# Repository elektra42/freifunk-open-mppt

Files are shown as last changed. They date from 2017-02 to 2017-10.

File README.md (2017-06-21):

These are preliminary sources and CAD files from the
Freifunk-Open-MPP-Tracker project.

## SOME LICENSE-FOO:
This is a Open-Source and Open-Hardware project under General Public License
v2 and Creative Commons - Attribution - ShareAlike 3.0.
For more information, check out the LICENSE file.

## A QUICK OVERVIEW OF THE DIRECTORIES:

#### AVR-FUSES
Contains a XML configuration file to program the fuses of the AVR. I am
using the AVR dragon board and AVR-Burn-O-Mat software to program the fuses.

#### SCHEMATIC AND BOARD
Electronic CAD files and component libraries, made with KiCAD. KiCAD is a free and
open ECAD tool.  Due to the intend to provide a open hardware and open
software project for DIY home-brewers, I have decided to use a free and open
source ECAD software tool, too. It is my first project with KiCAD, though.

#### uC-SOURCECODE
AVR-GCC source and Makefile. 

## SOME NOTES ABOUT THIS DESIGN
Basically this hardware has two building blocks: 
The MPP controller section and the buck converter.

At the moment, the buck converter section is based on the el cheapo and
low-fi MC33063 controller chip.  It can easily be replaced by a faster and
more fancy switch converter IC to construct a more powerful and slightly more 
efficient buck converter section.  However, with the external powerful P-MOS
switches, the efficiency was already around 94% with the first prototype 
(measured at 2 Ampere output current).

One reason to replace the MC33063 might be noise. Under low load, the
MC33063 will skip pulses of the PWM, so the switching frequency becomes
audible. 

# External references

* https://wiki.freifunk.net/Freifunk-MPP-Tracker
* https://wiki.freifunk.net/Freifunk-Mast

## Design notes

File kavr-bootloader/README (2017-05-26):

About this project
==================

kavr is an open source AVR boot loader written entirely in C. 
kavr supports updating firmware by sending hexfiles to the AVR processor 
via its serial port. A three wire (RxD, TxD, GND) serial port connection 
is sufficient. 

No special software is required on the host PC. Any serial port terminal 
such as HyperTerminal, Minicom etc. supporting XON/XOFF work fine with 
kavr. Even DOS commands (MODE, COPY) can be used.

License
=======

This program is free software: you can redistribute it and/or modify
it under the terms of the GNU General Public License as published by
the Free Software Foundation, either version 3 of the License, or
(at your option) any later version.

This program is distributed in the hope that it will be useful,
but WITHOUT ANY WARRANTY; without even the implied warranty of
MERCHANTABILITY or FITNESS FOR A PARTICULAR PURPOSE.  See the
GNU General Public License for more details.

You should have received a copy of the GNU General Public License
along with this program.  If not, see <http://www.gnu.org/licenses/>.

How kavr works
==============

kavr is an AVR boot loader. At reset, the AVR processor executes the code at 
the reset vector. Depending on fuse settings, the reset vector points at 
address zero (if no boot loader is used) or the reset vector points at an 
address in upper flash memory. This is where kavr resides.

kavr itself needs to be programmed into the AVR processor using a hardware 
programmer such as any programmer supported by avrdude. Once installed, kavr 
interrupts the boot process for a short time checking for hexfile records 
received on the serial port. If so, kavr programs any received hexfile data
into flash memory and then boots the new firmware application. If there are 
no hexfile records detected on the serial port, kavr boots the old firmware 
application as usual.

How to update firmware with kavr
================================

In order to load new firmware into your board running the kavr boot loader
you need to first generate a firmware hexfile. If not already part of your
firmware makefile, add a command like this:

    avr-objcopy -j .text -j .data -O ihex firmware.elf firmware.hex

Then, connect your board with a PC using a serial port cable. Run the 
terminal program of your choice on the PC. Configure the serial port for
the baud rate hardcoded in your kavr boot loader and configure 8N1 protocol
and xon/xoff (aka software) handshake. Example (DOS command prompt):

    C:\>mode com1 baud=9600 DATA=8 PARITY=n STOP=1 XON=on

Next, reboot your board. Before the timeout hardcoded into your kavr boot 
loader, send your firmware hexfile to the serial port. kavr will flash the
new firmware and then run it. Example (DOS command prompt):

    C:\>copy firmware.hex com1:

Roll your own kavr
==================

Are you ready to put kavr on your board? I am assuming you've got a recent 
WinAVR installed on your development machine and that you know how to use 
it. You will also need a hardware programmer supported by avrdude. 

First, tell kavr a few things about your board (clock params, MCU type...).
Update the first parameters in the kavr Makefile with your parameters. Here 
you will also need to define settings for serial port baud rate and boot 
loader timeout. Which one you choose depends on the capbilities of your board 
and its typical firmware application. I typically use 9600 baud and 1 second
timeout. Higher baud rates might or might not work, depending on your board's 
clock configuration. 

Then, build kavr for your board. Type "make". If there are any errors in the
make process, go fix them. The makefile displays the amount of flash used for
kavr (avr-size, the number under "text" matters). This number should be 
compatible with your boot loader start address (BOOTADDR) setting in the 
makefile and with your fuse settings. More specifically, BOOTADDR+size must 
not exceed your flash address space. Currently the code fits into 512 bytes 
(256 words) but this number may vary with your settings and with the compiler 
version you are using. Always double check that kavr fits into your flash.

Next, hook up your hardware programmer with your board. Run "make flash". 
This installs kavr into the boot loader area of your board. Now, tell AVR
to boot kavr instead of the firmware by programming its fuses for kavr mode.
Run "make fuse". 

Done! kavr should now be a happy boot loader on your system. Please note 
that when you flash kavr, avrdude also erases your firmware image so you 
will need to re-install your firmware.

Bugs/Enhancements?
==================

kavr is open source software. It's licensed under GPL. The latest source 
code is available on Sourceforge (http://kavr.sourceforge.net).
Please report any problems or feedback any proposals for enhancement using
the Sourceforge tracker system.

Donate
======

If you like kavr and if you use kavr for a project that you (or your 
employer) make money with, then you (or your employer) may want to consider 
donating a few bucks in return.

Your donation will help offsetting development costs, hardware purchases, 
and other expenses (like travel to conferences) in support of ongoing 
development of the software.

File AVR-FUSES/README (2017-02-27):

The XML file contains the fuse AVR description for the free AVR8-Burn-O-Mat tool.

URL: http://avr8-burn-o-mat.aaabbb.de/

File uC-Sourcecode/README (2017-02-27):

These files are for AVR-GCC. 

USE:

* Run 
$ make 
to compile

* Run 
$ make program
to write into the uC.

Programmer is set to avr-dragon by default. You can change this in the
Makefile. 

NOTE: You have to program the ATMega 8 fuses first.

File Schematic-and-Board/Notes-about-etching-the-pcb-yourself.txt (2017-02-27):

Etching the board yourself
++++++++++++++++++++++++++

This is cheap and fun and you don't have to wait for the pcb manufacturer to make your board.

The back side of the pcb is ground. I haven't filled the backside with copper yet. You can make a DIY 2-layer copy of the pcb board by etching only the top side. If you do that, you have to manually remove the copper around the pin holes of the pin headers that aren't connected to the ground on the back side of the pcb. You can do that manually with a relatively large drill by hand. Drill the small holes (0,8mm diameter), then use the large drill to cut away the copper by hand. 

The GND pins of the pin headers need to be soldered on the top and the bottom. The other pins need to be soldered at the top.

On the two protoype boards that I'm currently testing and experimenting with, I made the vias by drilling holes and soldering wire bridges to both sides.

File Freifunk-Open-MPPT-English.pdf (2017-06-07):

# Freifunk-Open-MPPT

## (MPPT: Maximum Power Point Tracker)

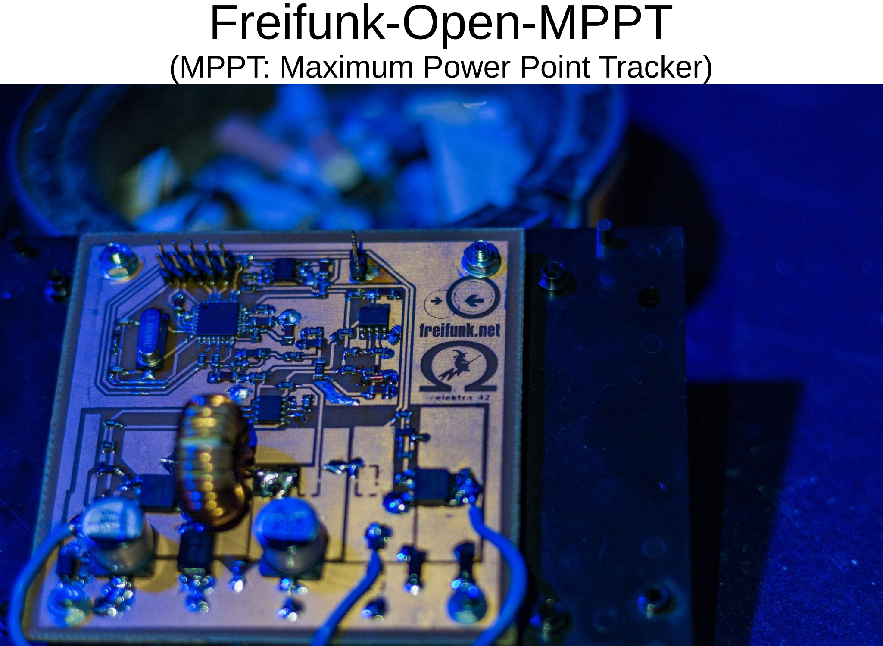
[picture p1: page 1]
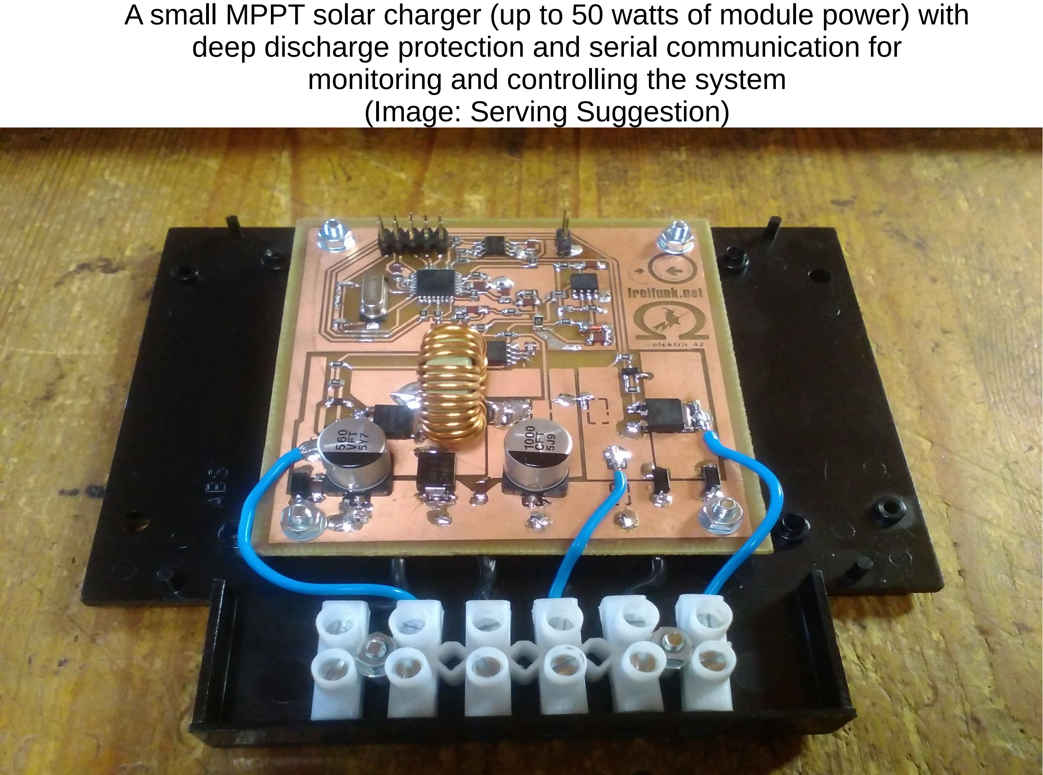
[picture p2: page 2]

A small MPPT solar charger (up to 50 watts of module power) with deep discharge protection and serial communication for monitoring and controlling the system (Image: Serving Suggestion)

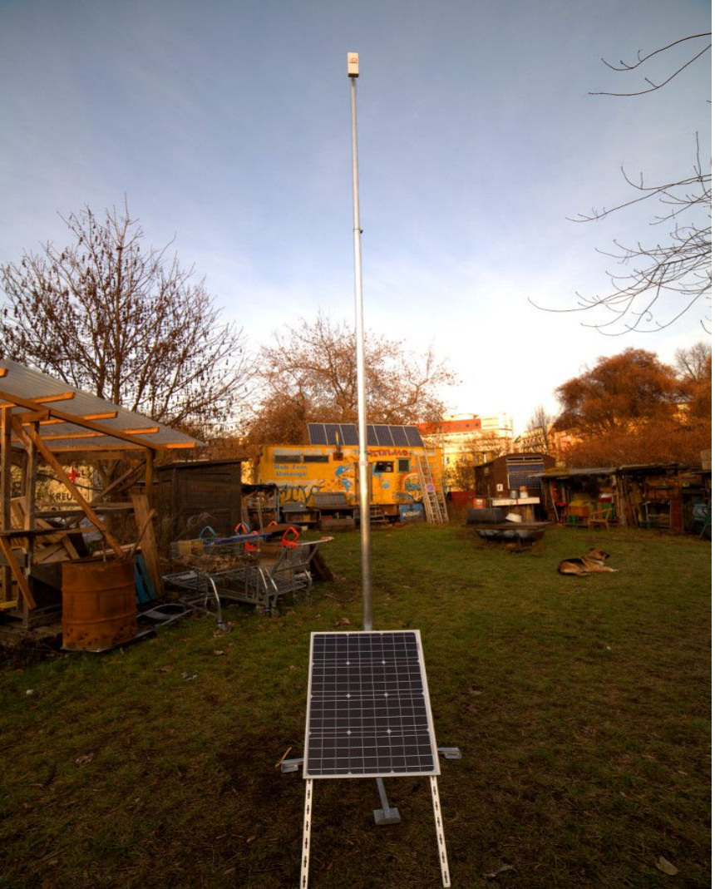
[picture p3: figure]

## Solar charger & measurement data acquisition for resilient and energy autonomous wireless

mesh nodes.

## Increased energy yield through Maximum Power Point Tracking

## Image: Mobile Freifunk mast

### Some applications for energy independent mesh nodes

### * Refugee camps

### * Resilient communication infrastructure / networks in crisis and disaster situations

### * Informal settlements in developing countries (controller provides electricity for smartphone, tablet, light, radio,... and mesh node on the roof)

### * Community network nodes at elevated locations without current, e.g. Barn roof, on the hill / mountain between two places that blocks the Fresnel zone

### * General purpose solar charger

* You name it.

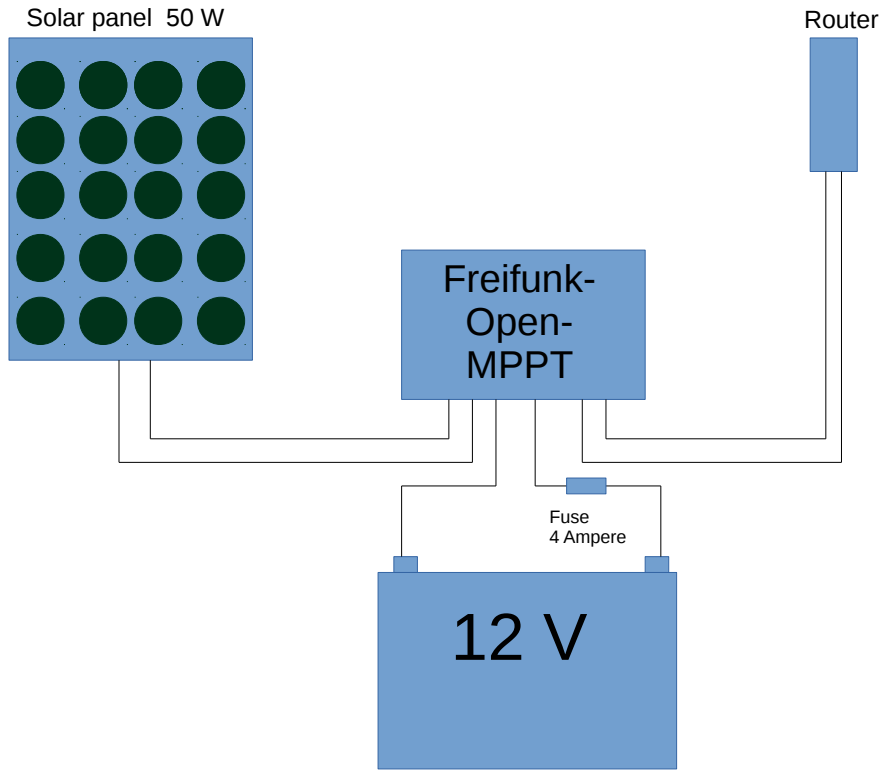
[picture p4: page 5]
Solar panel 50 W; Freifunk- Open- MPPT; Router; Fuse 4 Ampere

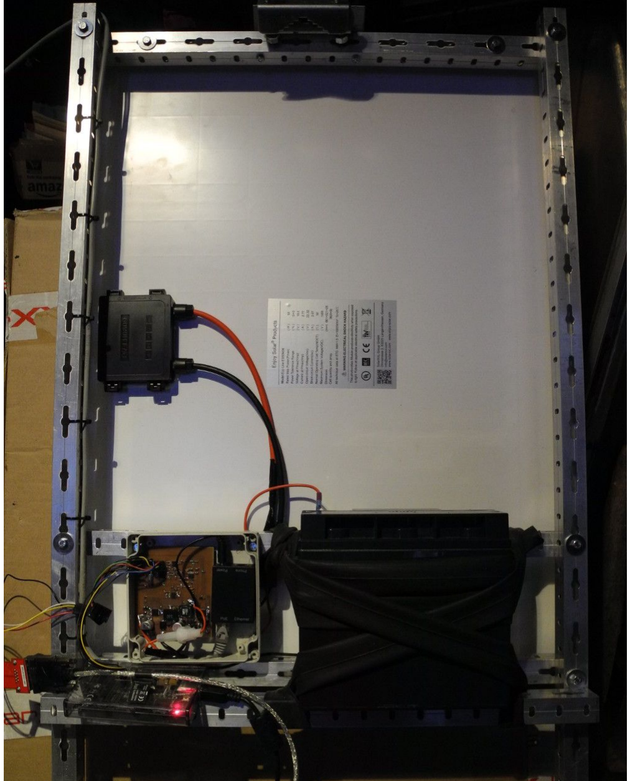
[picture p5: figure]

## Special features of the Freifunk-Open-MPPT:

* AVR-GCC Source code for μC firmware under GNU-GPL
* Open source CAD files for KiCAD (open-source -CAD program for Linux, Mac,
Windoze)
* MPPT design of the solar controller increases energy yield (94.5% efficiency)

* Communicates operating data via serial RS232 interface (3.3 volt level) e.g. To the connected router with the mesh network
* Uses only proven and easily available standard components
* Board layout, which allows the two-layer PCB in the DIY process itself (Milling or etching in the maker space on only one board side)
* Microprocessor-controlled: AVR ATmega8 with 1kByte RAM and 8kByte Flash (!)
* Firmware update via serial interface and bootloader, easy to do via serial upload (cat main.hex> / dev / tty ***) within 8 seconds after activating the power supply

# MPPT – what?!

Electric power in watts is voltage times Power:

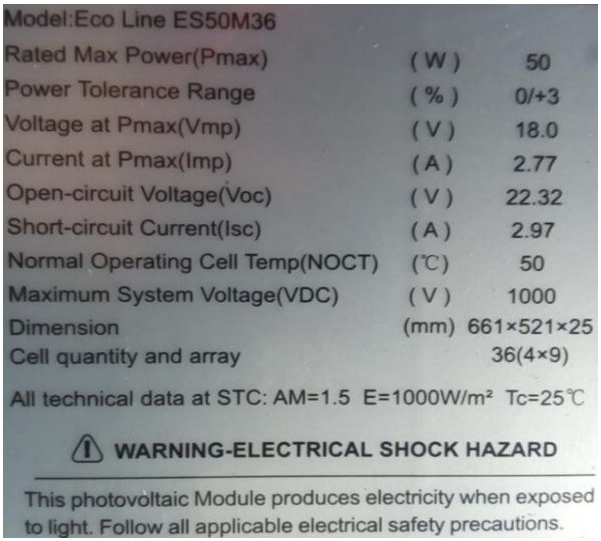
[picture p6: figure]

Watt = Volt * Ampere

50 W solar module specs:

Battery voltage = 11.3 - 14.9V

### 50 Watt Solar module at MPP:

### 50 W = 18V * 2.77A

### 50 Watt solar module

connected to 12 V battery
voltage without MPPT:

### 33.24 W = 12 V * 2.77 A

### 50 Watt Solar module with

Freifunk-Open-MPPT (94.5%
efficiency):

### 47.12 W = 18V * 2.77A * 0.945

## MPPT in operation

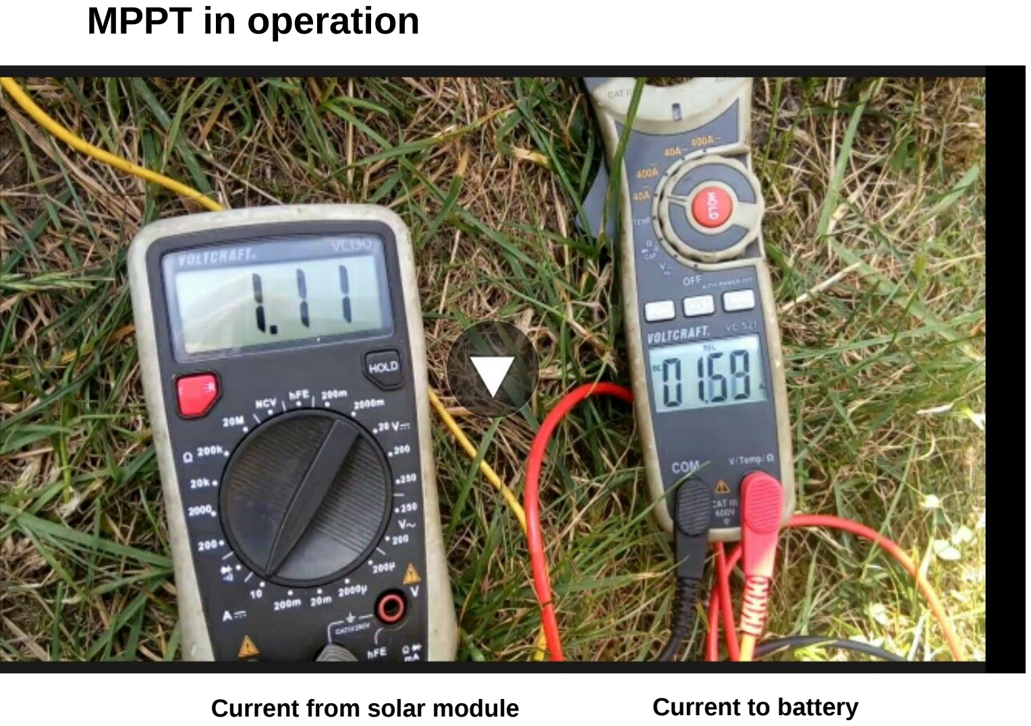
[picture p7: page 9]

Current from solar module | Current to battery

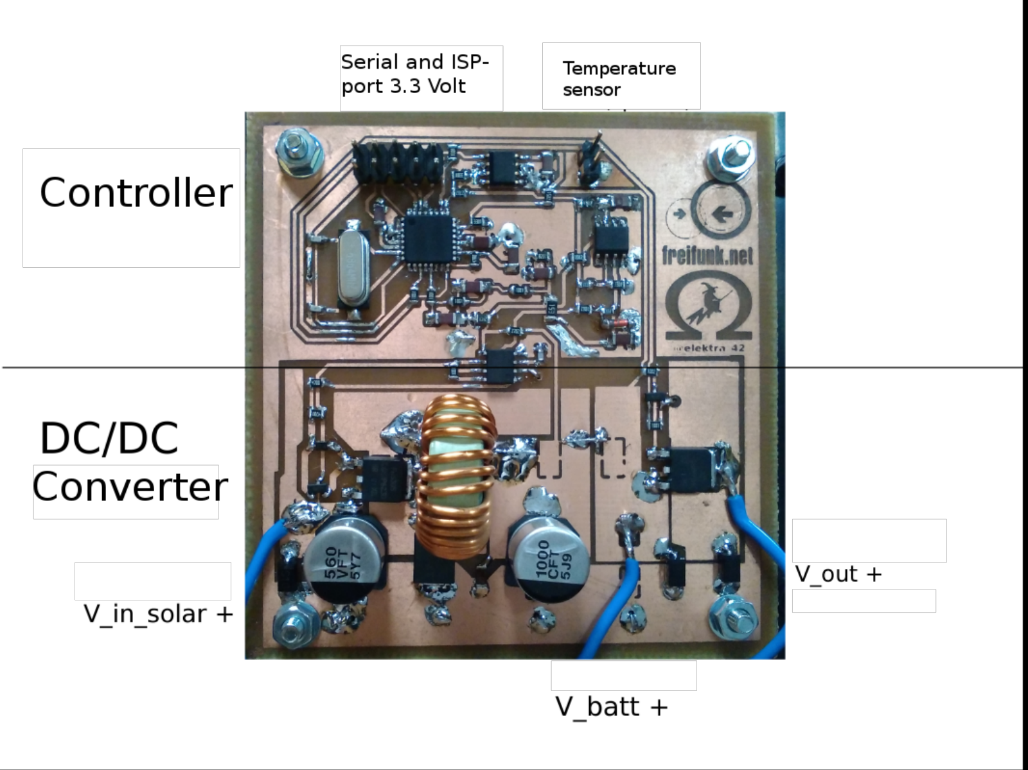
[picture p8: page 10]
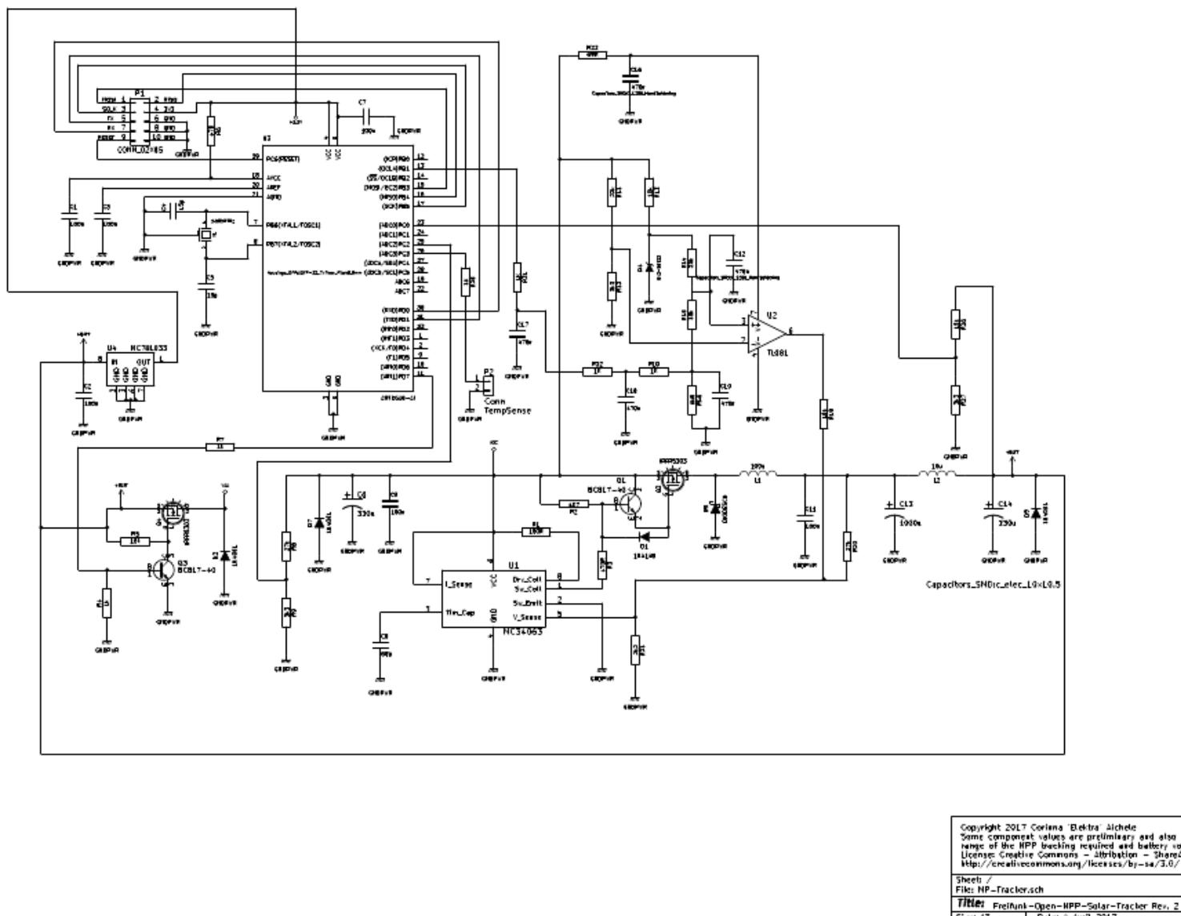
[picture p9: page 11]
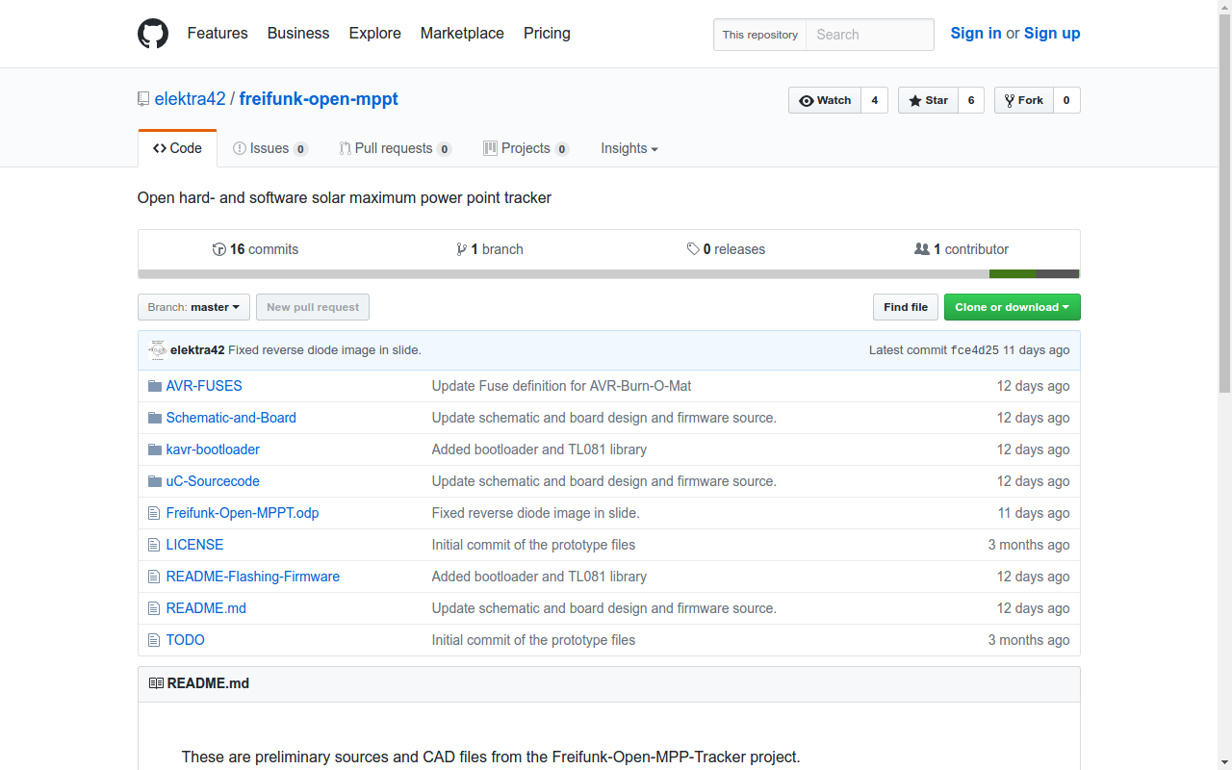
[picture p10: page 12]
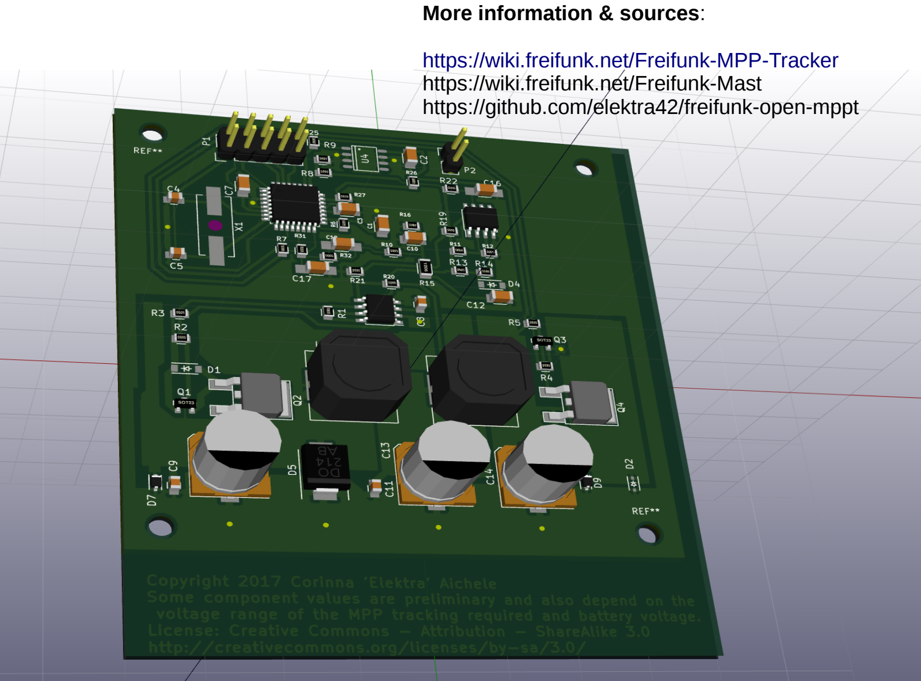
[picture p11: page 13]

More information & sources:

https://wiki.freifunk.net/Freifunk-MPP-Trackerhttps://wiki.freifunk.net/Freifunk-Masthttps://github.com/elektra42/freifunk-open-mppt

# Thank you for your attention!

# @elektra_42

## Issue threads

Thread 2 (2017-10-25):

not really an issue but ...

5chufti, 2017-10-25:
it would be nice to have some explanation about the function around PB1 - R/C filter/integrator - U2 - R11..R15/D4 - Vsense. I looked at the "homepage", found good explanation about mppt, but none about theory behind "feedback/control" circuitry.

elektra42, 2017-10-26:
The R/C filter network provides a stable and low noise reference voltage for the V+ input of the OP-Amp, which is controlled by the PWM output of the µC. Since the OP-Amp has no symmetrical power supply, a bit of trickery at the voltage divider is necessary to put the PWM signal of the µC, which can not exceed 3.3 V, to a level that is high enough about GND to be compared by the V- input of the OP-Amp, which is connected to the solar input rail via a voltage divider. If the V+ input is greater than the V- input of the OP-Amp, the input solar voltage is lower than the set MPP point. The output of the OP-Amp goes up, signalling the DC/DC buck controller chip MC33063 via its reference pin that the set output voltage has been exceeded. In response, the MC33063 will reduce the pulse-pause-ratio of the PWM in the MC33063, hence the current load on the solar module will go down and the solar input voltage rises to the point where V- at the Op-amp becomes greater then V+. V out of the OP-Amp goes down: So here we have a control loop, controlling the MPP voltage.

By controlling the PWM output of the µC, the MPP input voltage can be controlled by the µC firmware.

5chufti, 2017-10-26:
thank you for the quick answer.

Closed 2017-10-26.

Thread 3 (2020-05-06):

100W or even more - which parts to be changed on the PCB?

fafu, 2020-05-06:
Hi all,
since 100W solar panels are only slightly more expensive than a 50W panel I am curious which parts to be changed. If I remember right, elektra told me during a workshop it is possible.

Thanks :)

elektra42, 2020-05-10:
You should replace C6, Q2 and C13. Replace C6 with a polymer electrolytic capacitor, they have lowest ESR compared to the stock low ESR capacitor. Recommended: PANASONIC SVPF 330µ 25 V. Replace C13  with a polymer electrolytic capacitor. Recommended: PANASONIC SVPF 1000µ 16V , Replace Q2 with AO D403 MOSFET, P-CH, 30V, 70A, 90W, DPAK.

Make sure to not exceed 25 V idle (open connector = Voc) solar panel voltage in sunny, but freezing cold climate (sunny winter day). The absolute maximum voltage limit of SVPF 330µ 25 V is 29 V. You should avoid getting close to that limit. If you risk 26 or even 27 V idle under rare conditions, that might be ok. Keep an eye on L1, on my tuned FF-OpenMPPTs, I have used a larger ring power core with thicker wire, so I'd recommend that, too. But you might get away with the stock L1. If you buy a bigger ring power core L1 could be winded to ~16µH, if possible with thicker insulated copper wire. The thicker the wire you can make fit, the better (more efficient).

As I sidenote: I have a new design with a ESP32 build in and prepared for more power. https://github.com/ISEMS/ISEMS-ESP32

Have fun and success with soldering.

Sunshine!
Elektra

elektra42, 2020-05-10:
One more note: The material for the ring power core is critical. So don't use just a random ring power core that comes your way. I recommend Micrometals/Amidon power core material type "-18", a T 94-18 should handle the power well.

fafu, 2020-05-17:
Thank you for the helpful information

Closed 2020-05-17.

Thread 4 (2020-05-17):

Max current on v-out?

fafu, 2020-05-17:
Hi,
what is the max current which can be drawn on v-out?

elektra42, 2020-05-17:
RDS_on is 0.06 Ohm for the stock IRF5305. For a output current of 5 Ampere this means a voltage drop of 0.3 V and a power loss of 1.5 Watt. You can upgrade to a AO D403 here, too, which has 0.008 Ohm RDS_on. That results in a voltage drop of 0.08 V at 10 Ampere, hence a power loss of 0.8 Watt. I recommend not to go higher than that.

Closed 2020-05-17.

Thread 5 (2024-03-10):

[Feature] DC-Mini-Grid input/output?

T-X, 2024-03-10:
It'd probably be out of scope for this project right now, but had been wondering if such an addition would be technically doable or what the challenges could be to achieve it:

Add an additional two +/- pins which could be used to interconnect multiple Freifunk Open-MPPT devices to a distributed mini DC grid. If one or more devices have batteries charged to a high State-of-Charge (like >75%?) they'd provide it to other devices with batteries with a low State-of-Charge (<50%?).

1) Should likely be using 56VDC - 60VDC to be able to achieve a bit of distance, to reduce losses?
2) Would it maybe make sense to somehow limit the current in a smart way to reduce losses (and as a safety feature, to reduce the risk of running too much current through the wires?)?

I'm also wondering what the advantages and disadvantages would be to design it in a "Hub mode" where every device connects to the same line (1:n). Versus a "Switch mode" with multiple +/- pairs on a device and then only peer-to-peer 1:1 connections. (The latter would probably make 2) as a safety feature easier to implement and monitor, but would also be more costly?)

**Problems this feature could solve**

For instance in a trailer park scenario involving trees not everyone has the same amount of usable space for solar panels available. Also it's not always easy to estimate the needed battery and panel sizes in advance, power requirements can change over time. Thirdly, this could make it more easy/flexible/manageable to use/add multiple Open-MPPT devices to locally power multiple Freifunk routers, laptops, Raspberry Pis etc.?

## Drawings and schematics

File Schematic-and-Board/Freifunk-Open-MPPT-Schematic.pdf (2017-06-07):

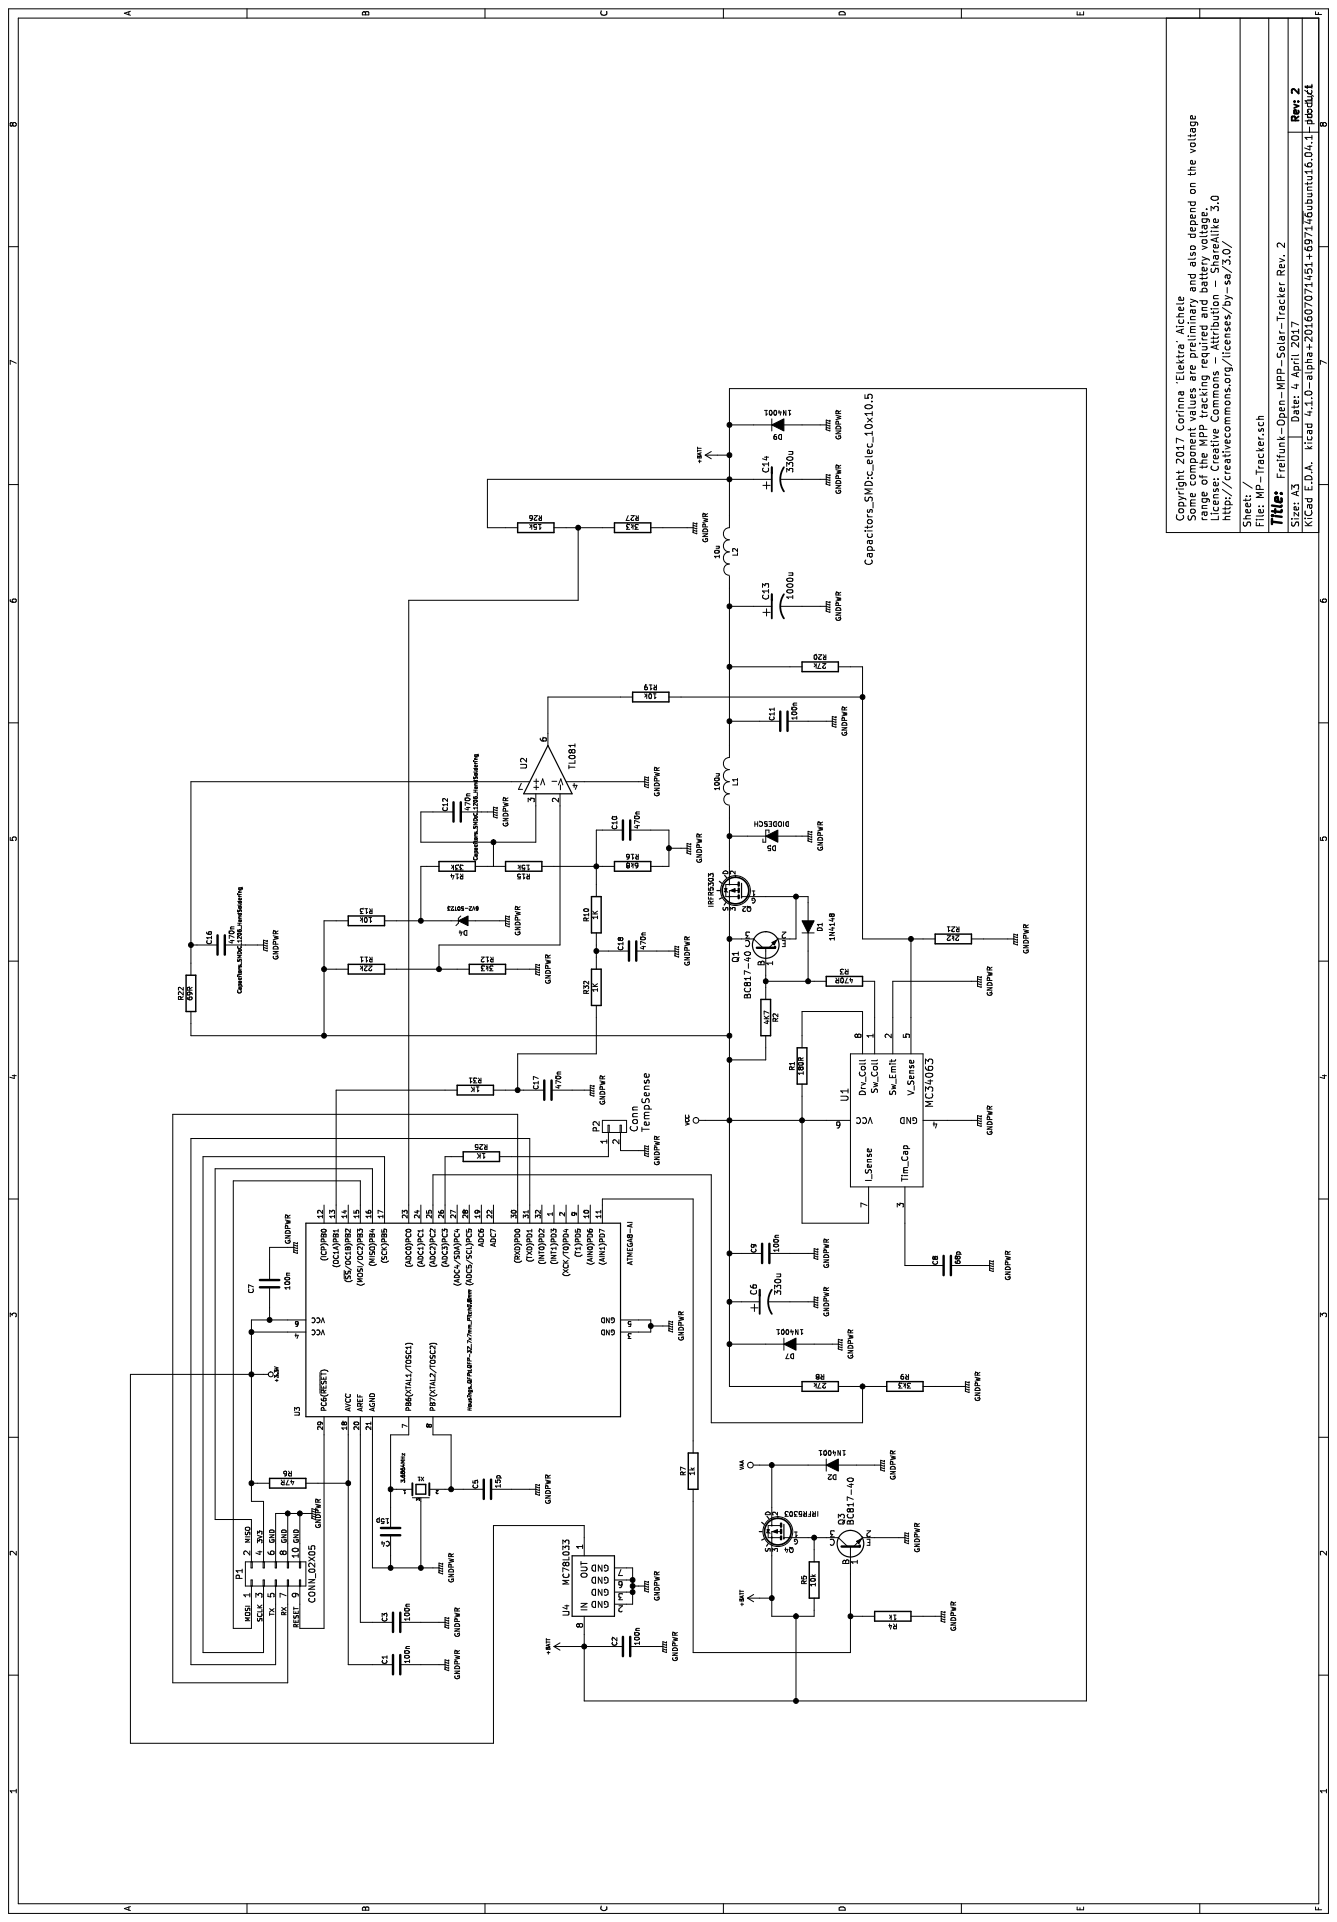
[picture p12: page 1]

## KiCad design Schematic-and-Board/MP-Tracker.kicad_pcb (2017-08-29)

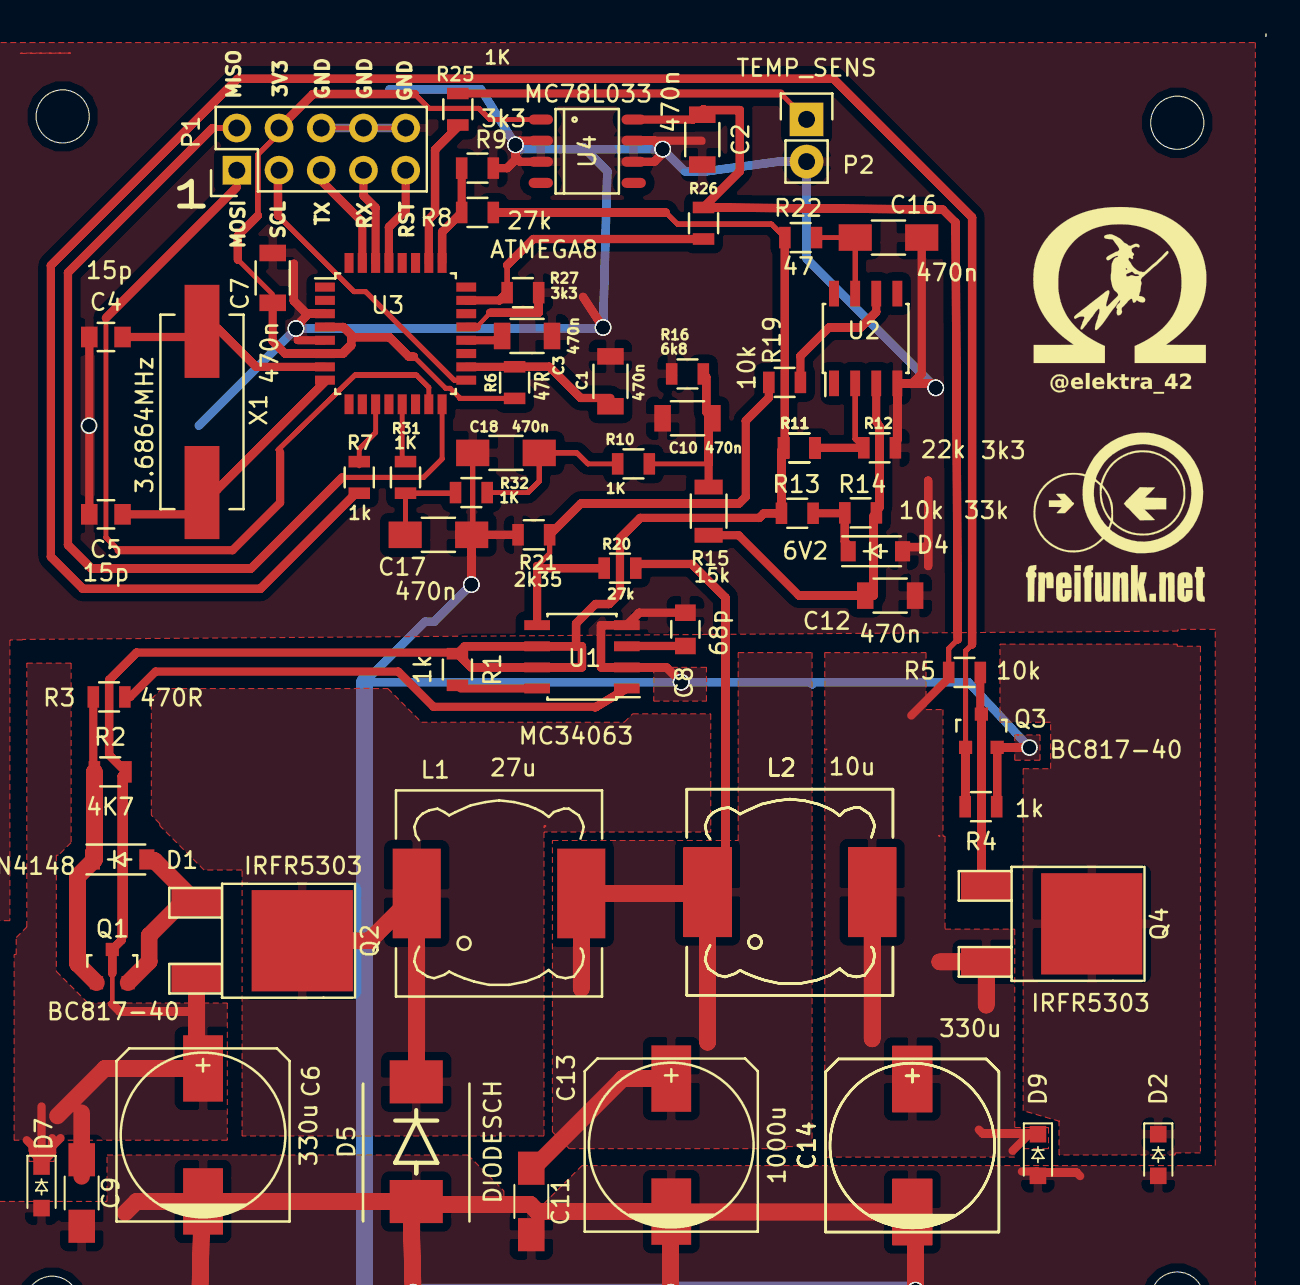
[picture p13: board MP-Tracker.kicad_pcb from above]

Board: 2 copper layers, 64 parts (0 on the bottom side), 39 nets.

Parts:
C1, C2, C3, C7, C10, C12: 470n; C_1206
C4, C5: 15p; C_0805
C6, C14: 330u; c_elec_10x10
C8: 68p; C_0805
C9, C11: 100n; C_1206_HandSoldering
C13: 1000u; c_elec_10x10
C14#2: c_elec_10x10
C16, C17, C18: 470n; C_1206_HandSoldering
D1: 1N4148; SOD-123
D2, D7, D9: 1N4001; D_SOD-323_HandSoldering
D4: 6V2; SOD-123
D5: DIODESCH; DO-214AB
L1: 27u; Choke_SMD_12x12mm_h8mm
L2: Choke_SMD_12x12mm_h8mm
L2#2: 10u; Choke_SMD_12x12mm_h8mm
P1: Pin_Header_Straight_2x05
P2: TEMP_SENS; Pin_Header_Straight_1x02
Q1, Q3: BC817-40; SOT-23
Q2, Q4: IRFR5303; TO-252-2Lead
R1, R4, R7: 1k; R_0805
R2: 4K7; R_0805
R3: 470R; R_0805
R5, R13, R19: 10k; R_0805
R6: 47R; R_0805
R8, R20: 27k; R_0805
R9, R12, R27: 3k3; R_0805
R10, R25, R31, R32: 1K; R_0805
R11, R11#2: 22k; R_0805
R14: 33k; R_0805
R15: 15k; R_1206
R16: 6k8; R_0805
R21: 2k35; R_0805
R22: 47; R_0805
R26: 15k; R_0805
U1: MC34063; SOIC-8_3.9x4.9mm_Pitch1.27mm
U2: TL081; SOIC-8-1EP_3.9x4.9mm_Pitch1.27mm
U3: ATMEGA8; LQFP-32_7x7mm_Pitch0.8mm
U4: MC78L033; SO-8
X1: 3.6864MHz; Crystal_HC49-SD_SMD

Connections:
+3.3V: C7.1, P1.4, R6.1, U3.4, U3.6, U4.1
+BATT: C2.1, C14.1, C14#2.1, D9.1, L2.2, L2#2.2, Q4.3, R5.1, R26.1, U4.8
GNDPWR: C1.2, C2.2, C3.2, C4.1, C5.2, C6.2, C7.2, C8.2, C9.2, C10.2, C11.2, C12.2, C13.2, C14.2, C14#2.2, C16.2, C17.2, C18.2, D2.2, D4.2, D5.1, D7.2, D9.2, P1.6, P1.8, P1.10, P2.2, Q3.2, R4.1, R9.2, R12.2, R16.2, R21.2, R27.2, U1.2, U1.4, U2.4, U3.3, U3.5, U3.21, U4.2, U4.3, U4.6, U4.7
unnamed: C1.1, R6.2, U3.18
unnamed: C3.1, U3.20
unnamed: C4.2, U3.7, X1.1
unnamed: C5.1, U3.8, X1.2
unnamed: C8.1, U1.3
unnamed: C10.1, R10.2, R15.1, R16.1
unnamed: C11.1, C13.1, L1.2, L2.1, L2#2.1, R20.1
unnamed: C12.1, R14.1, R15.2, U2.3
unnamed: C16.1, R22.2, U2.7
unnamed: C17.1, R31.2, R32.1
unnamed: C18.1, R10.1, R32.2
unnamed: D1.2, Q1.2, Q2.1
unnamed: D1.1, Q1.1, R2.1, R3.1
unnamed: D4.1, R13.2, R14.2
unnamed: D5.2, L1.1, Q2.2
unnamed: P1.1, U3.15
unnamed: P1.2, U3.16
unnamed: P1.3, U3.17
unnamed: P1.5, U3.31
unnamed: P1.7, U3.30
unnamed: P1.9, U3.29
unnamed: P2.1, R25.2
unnamed: Q3.1, R4.2, R7.1
unnamed: Q3.3, Q4.1, R5.2
unnamed: R1.2, U1.8
unnamed: R3.2, U1.1
unnamed: R7.2, U3.11
unnamed: R8.2, R9.1, U3.25
unnamed: R11.2, R11#2.2, R12.1, U2.2
unnamed: R19.1, U2.6
unnamed: R19.2, R20.2, R21.1, U1.5
unnamed: R25.1, U3.26
unnamed: R26.2, R27.1, U3.23
unnamed: R31.1, U3.13
VAA: D2.1, Q4.2
VCC: C6.1, C9.1, D7.1, Q1.3, Q2.3, R1.1, R2.2, R8.1, R11.1, R11#2.1, R13.1, R22.1, U1.6, U1.7

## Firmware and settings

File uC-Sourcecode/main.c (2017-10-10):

/* **********************************************************************
 * AVR-GCC source code for Freifunk-Open-MPP-Solar-Tracker
 * Copyright (C) 2017  by Corinna 'Elektra' Aichele 
 * 
 * This file is part of the Open-Hardware and Open-Software project 
 * Freifunk-Open-MPP-Solar-Tracker.
 * 
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
 * This source code is distributed in the hope that it will be useful,
 * but WITHOUT ANY WARRANTY; without even the implied warranty of
 * MERCHANTABILITY or FITNESS FOR A PARTICULAR PURPOSE.  See the
 * GNU General Public License for more details.
 * You should have received a copy of the GNU General Public License
 * along with this source file. If not, see http://www.gnu.org/licenses/. 
 *************************************************************************/


#include <avr/io.h>
#include <stdlib.h>
#include <util/delay.h>
#include <avr/sleep.h>
#include <avr/interrupt.h>

/* UART init */

#ifndef F_CPU
#warning "F_CPU not defined in Makefile. Using 3.686400 MHz"
#define F_CPU 3686400UL 
#endif

/* Define baud rate for serial port */
#define BAUD 9600UL

/* Calculate UART BAUD register setting */
#define UBRR_SETTING ((F_CPU+BAUD*8)/(BAUD*16)-1)



    uint16_t v_out_adcval;
    uint16_t solar_in_adcval;
    uint16_t v_in_value;
    uint16_t v_out_value;
    char vo[] = "";
    
    /* All Voltages are in mV */
    
    // v_out_max = Charge end voltage in mV at 25 degrees Celsius for sealed VRLA 12 V battery (Kung-Long, Panasonic and the like)
    // Manufacturers recommend 14.7 V to 14.9 V charge end voltage for cyclic use, 13.6 V to 13.8 V for standby use
    // As a solar system is a mix between cyclic and standby use, 14.15 V - 14.3 V charge end voltage is probably a good compromise.
    
    uint16_t v_out_max = 14200; 
    
    // v_load_off = Low voltage disconnect voltage in mV. Battery wear depends on depth-of-discharge. 11.7 Volt is moderate, discharging will stop at approximately 15% charge. For extended battery life, v_load_off can be increased to 12.1 V (~50% charge). Lead acid batteries have no memory effect.

    uint16_t v_load_off = 11700; 
    
    // v_load_on = Low voltage disconnect enable voltage in mV. v_load_off and v_load_on are building a hysteresis so the system doesn't turn the load on and off repeatedly. 
    
    uint16_t v_load_on = 12300; 
    
    
    uint16_t v_mpp_estimate = 0;
    uint8_t step = 0x1;
    volatile uint16_t ticks = 0;
    double ptc_resistance;
    double resistor_voltage;
    double temperature;
    double temp_deviation;
    uint16_t v_out_max_temp;
    uint16_t old_mpp_pwm_val =0;
    uint16_t count;
    

/* ADC init */
void ADC_Init(void)
{
  // Reference: Use Vcc as AVcc
  ADMUX = (1<<REFS0);    
  
  /* Bit ADFR ("free running") in ADCSRA is zero 
   * by default which means single conversion */
  
  // Enable frequency divider
  ADCSRA = (1<<ADPS1) | (1<<ADPS0);
  // set ADC enable
  ADCSRA |= (1<<ADEN);                             

  /* After activating the ADC, a warm-up readout is 
   * recommended to increase accuracy */
  
  // run ADC readout
  ADCSRA |= (1<<ADSC);
  // wait until finished
  while (ADCSRA & (1<<ADSC) ) {               
  }
}



/* ADC read, single conversion */
uint16_t ADC_Read( uint8_t channel )
{
  /* Select ADC channel */
  ADMUX = (ADMUX & ~(0x1F)) | (channel & 0x1F);
  // single conversion
  ADCSRA |= (1<<ADSC);
  // wait for conversion until finished
  while (ADCSRA & (1<<ADSC) ) {             
  }
  return ADCW;
}



/* Multiple ADC readouts, calculate average  */
uint16_t ADC_Read_Avg( uint8_t channel, uint8_t nsamples )
    {
    uint32_t sum = 0;

    for (uint8_t i = 0; i < nsamples; ++i ) {
    sum += ADC_Read( channel );
            }

    return (uint16_t)( sum / nsamples );
    }


/* UART init */
void uart_tx_enable(void)
    {
        UBRRH = UBRR_SETTING >> 8;
        UBRRL = UBRR_SETTING & 0xFF;
	
	// enable UART TX
        UCSRB |= (1<<TXEN);
	// select asynchronous mode 8N1 
        UCSRC = (1<<URSEL)|(1<<UCSZ1)|(1<<UCSZ0);  // asynchronous mode 8N1 
        }

        
/* UART disable */
void uart_tx_disable(void)
    {
        UCSRB |= (0<<TXEN);  // disable UART TX 
        }
  
  

/* UART send single character */
int uart_putc(unsigned char c)
    {
        // wait until transmit is possible 
        while (!(UCSRA & (1<<UDRE)))  
        {
        }                             
	// send character
        UDR = c;                      
        return 0;
        }

    
/* UART send string */
void uart_puts(char *s) 
    {
        while (*s)
        {   //transmit as long as  *s != '\0' 
            uart_putc(*s);
            s++;
        }
    }
    

    
/* Low voltage disconnect */                    
void low_voltage_disconnect (uint16_t voltage)
    {
	
        // Exceeding v_load_on enables load
	if (voltage > v_load_on) 
        { 
        PORTD = (1<<PD7) ;
        }
        
        // Below v_load_off, disable load      
        if (voltage < v_load_off) 
        {
        PORTD = (0<<PD7);
        }
        
        // Let the world know (if it has power to read the data ;)
        if (PORTD == (1<<PD7))
        {
        uart_puts("Load enabled\r\n");
        }
        else 
        {
        uart_puts("Load disabled\r\n");
        }
                    
    }

/* Power saving sleep routine based on counter/timer2 
 * Sleep (idle) time with 3.684 MHz clock is 70.6ms */
void interrupt_based_sleep (void)
	{
  
	TIFR |= (1<<TOV2);
	// enable counter2 overflow interrupt
	TIMSK |= (1<<TOIE2);
	// Set counter2 to zero
	TCNT2 = 0x00;
	sei();  
	set_sleep_mode(SLEEP_MODE_IDLE);
	sleep_enable();
	sleep_mode();
	cli();
	}

/* ISR TIMER2 overflow routine */
ISR(TIMER2_OVF_vect)
      {
      return;
      }
      
/* Measure battery voltage */
 uint16_t measure_v_out(void) {
	v_out_adcval = ADC_Read_Avg(0, 32); 
	v_out_value = (17.57 * v_out_adcval);
        return v_out_value;
}

/* Measure solar input voltage */
uint16_t measure_v_in(void) {
        // Read ADC channel 2, calculate average from 10 readings
        solar_in_adcval = ADC_Read_Avg(2, 32);  
        v_in_value = (29.13 * solar_in_adcval);
        return v_in_value;
    
}

void read_temp_sens (void)
    {
        /* Read voltage of ptc resistance in voltage divider
         * Suggested PTC temperature sensor model:  KTY 81-210
         * R2 = PTC resistance at 25 degrees Celsius 2000 Ohm +- 20 Ohm
         * R1 = 1300 Ohm 
         * R2 = R1 / ((3300mV / resistor_voltage) - 1) 
         * all values in mV */
        
        
        resistor_voltage = (ADC_Read_Avg(3, 8)) * 3.22265 ;
        
        if (resistor_voltage > 3200) {
        uart_puts ("No temperature sensor available. \r\n");
        return;
        }
        
         uart_puts("PTC sensor voltage: ");
	 itoa(resistor_voltage, vo, 10 );
	 uart_puts(vo);
	 uart_puts (" mV\r\n");
         ptc_resistance = 1300 /  ((3300 / resistor_voltage) - 1);

         uart_puts("PTC sensor resistance: ");
         itoa(ptc_resistance, vo, 10 );
         uart_puts(vo);
         uart_puts (" Ohm\r\n");
       
        // KTY 81-210 is not very accurate.
        // Best accuracy at 40 degrees Celsius
         
        temperature = -30 + ((ptc_resistance - 1247) / 14.15);
        
        uart_puts("Temperature ");
        dtostrf (temperature, 1, 1, vo);
        uart_puts(vo);
        uart_puts (" degrees Celsius\r\n");
        
        /* Calculate and adjust charge end voltage depending on 
        battery temperature for voltage regulated lead acid battery chemistry 
        Correction factor 5 mV per cell for one degree Celsius 
        12 V lead acid type has 6 cells */
        
        if (temperature > 25.00) {
        v_out_max_temp = v_out_max - ((temperature - 25.00) * 30);
        }
        
        if (temperature < 25.00) {
        v_out_max_temp = v_out_max + ((25.00 - temperature) * 30);
        }
        
        uart_puts("Temperature adjusted charge end voltage: ");
        itoa(v_out_max_temp, vo, 10 );
        uart_puts(vo);
        uart_puts (" mV\r\n");
        
        
        
    }

                
                
void serialdatareport (void)
    {
        // Prevent serial data from getting garbled.
        _delay_ms(20);
        // Prepare UART for sending data 
        uart_tx_enable();
        measure_v_in();
        // convert to ascii using 10 for radix 10 -> decimalsystem
        uart_puts("V_in ");
        itoa( v_in_value, vo, 10 ); 
        uart_puts( vo );
        uart_puts(" mV""\r\n");

        measure_v_out();
        uart_puts("V_out "); 
        itoa( v_out_value, vo, 10 ); 
        uart_puts( vo );
        uart_puts(" mV""\r\n");

        uart_puts ("New PWM value: 0x");
        itoa(OCR1A, vo, 16 );
        uart_puts (vo);
        uart_puts ("\r\n");      

        uart_tx_disable();
        
        read_temp_sens();

        }
        

 void charge_end_limit (void) 
      {
	 /* Reduce charging current at V_out_max_temp */
	 
         measure_v_out();
	 
	 if (v_out_value > (v_out_max_temp + 20)) {
             
             OCR1A = old_mpp_pwm_val;
             count = 0;
             uart_puts ("In charge end loop \r\n"); 
             
             while(count < 65535) {
                 measure_v_out();
                 if (v_out_value > v_out_max_temp && OCR1A < 0x3FF ){
                    //uart_puts ("PWM UP by 1\r\n");
                    OCR1A += 0x1;}
                  
                if(v_out_value < v_out_max_temp && OCR1A > 0x1) {
                   //uart_puts ("PWM DOWN by 1\r\n"); 
                   OCR1A -= 0x1;}
                  
                  count++;
                  _delay_ms(1);
             }
            
            uart_puts("V_out "); 
            itoa( v_out_value, vo, 10 ); 
            uart_puts( vo );
            uart_puts(" mV""\r\n");            
            
            uart_puts("V_out at charge end voltage  ");
            itoa(v_out_max_temp, vo, 10 );
            uart_puts(vo);
            uart_puts ("mV\r\n");
            _delay_ms(1000);
            
            old_mpp_pwm_val = OCR1A;
            uart_puts("old_mpp_pwm_val "); 
            itoa(OCR1A, vo, 16 );
            uart_puts (vo);
            uart_puts ("\r\n");
    
      }
      }
      


int main(void)
{
    
    // Set up GPIOs PD7 and PB1 as output ports
    DDRD = (1<<PD7);
    DDRB = (1<<PB1);
    
    // Enable ADC
    ADC_Init();
    
    // Set up PWM1 to control refence voltage of OP-AMP
    TCCR1A|=(1<<COM1A1)|(0<<COM1A0)|(0<<WGM13)|(1<<WGM12)|(1<<WGM11)|(1<<WGM10);
    TCCR1B|=(1<<CS10);
    ICR1=0x3ff;
    OCR1A = 0xf0;
    
    // Enable Timer/Counter2 to generate interrups for timer based sleep
    TCCR2 |= ( 1<<CS02 )| ( 1<<CS01)| ( 1<<CS00 );  // Use counter2, set prescaler to 1024
    
    _delay_ms(200);
    
    v_out_max_temp = v_out_max;
    

        /* Main program loop */
        while (1) {
                 measure_v_out();
                 low_voltage_disconnect(v_out_value);
		 uart_puts("Parsed low voltage disconnect routine"); 
		 uart_puts ("\r\n");
		 
		 charge_end_limit();
		 
		 
		/* Check if there is actually power from the solar panel.
		 * If not, sleep for a while */
		/* First, measure solar input voltage */
		measure_v_in();
		
		 /* If solar power is coming in and 
		  * we didn't reach maximum output, 
		  * run the MPP routine */
		 
		if ((v_out_value < v_in_value) && (v_out_value < (v_out_max_temp - 20))) {
		  
		  /* Measure solar panel open circuit voltage 
		   * and calculate MPP point */
		  
		  OCR1A = 0x3FF;
		  _delay_ms(400);
                  measure_v_in();
		  uart_puts("V_in_idle "); 
		  itoa( v_in_value, vo, 10 ); 
		  uart_puts( vo );
		  uart_puts(" mV""\r\n");
		  v_mpp_estimate = v_in_value / 1.24;
		  
		  /* Set MPP to lowest possible point (PWM output of AVR = 0) */
		  
		  OCR1A = 0x0;
                  charge_end_limit();
		  _delay_ms(200);
                  measure_v_in();
		  uart_puts("Minimum V_mpp "); 
		  itoa( v_in_value, vo, 10 ); 
		  uart_puts( vo );
		  uart_puts(" mV""\r\n");
		  
		  /* Report calculated MPP and ramp up PWM until 
		   * we reach the calculated MPP input voltage */
		  
		  uart_puts("Calculated V_mpp "); 
		  itoa( v_mpp_estimate, vo, 10 ); 
		  uart_puts( vo );
		  uart_puts(" mV""\r\n");
		  measure_v_in();
                  measure_v_out();
		  
		  while ((v_in_value < v_mpp_estimate) && (v_out_value < (v_out_max_temp - 150)))  {
		    
		    OCR1A += step;
		    _delay_ms(10);
                    measure_v_in();
                    measure_v_out();
		    }
		    
                        ticks = 0;
                        uart_puts("MPP should be set");
                        uart_puts ("\r\n");
                        while (ticks != 100) {
                            interrupt_based_sleep();
                            _delay_ms(20);
                            charge_end_limit();
                            ticks ++;
                    
		}
		  }
		
		if (v_out_value > v_in_value)
		{
		ticks = 0;
		uart_puts("Going to sleep, input voltage too low");
		uart_puts ("\r\n");
		while (ticks != 200) {
                      interrupt_based_sleep();
		      ticks ++;
                  }
                
		}
		charge_end_limit();
                
		serialdatareport();
		_delay_ms(500);
            }

   return 0; // never reached 
        }

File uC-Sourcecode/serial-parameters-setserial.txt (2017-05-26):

/dev/ttyUSB0 uart 16654 port 0x0000 irq 0 baud_base 460800 spd_normal

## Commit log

2017-02-27 Initial commit of the prototype files
    [MP-Tracker.kicad_pcb, MP-Tracker.sch]
2017-02-27 Added a PDF of the schematic.
2017-03-01 Switched to interrupt based sleep (idle) routine instead of delay routine to save power.
2017-04-07 New procedure for maximum power point detection (faster, simpler, more efficient).
2017-04-07 New major revision of schematic. The most notable changes: Added three 3-step R/C filters to cancel noise from uC PWM and for current measurement. Switched from TL081 to MC4558 dual-OP-amp. (Better p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
    [MP-Tracker.sch]
2017-05-26 Added bootloader and TL081 library
    [serial-parameters-setserial.txt]
2017-05-26 Update Fuse definition for AVR-Burn-O-Mat
2017-05-26 Update schematic and board design and firmware source.
    [MP-Tracker.kicad_pcb, MP-Tracker.sch]
2017-05-27 Fixed reverse diode image in slide.
2017-06-07 Updated PDF document of the schematic.
2017-08-29 Updated firmware with temperature sensor support (KTY81-210) Minor fixes in the schematic.
    [MP-Tracker.kicad_pcb, MP-Tracker.sch]
2017-10-10 Improved regulating behavior at charge end, temperature controlled charge end voltage in µC firmware.

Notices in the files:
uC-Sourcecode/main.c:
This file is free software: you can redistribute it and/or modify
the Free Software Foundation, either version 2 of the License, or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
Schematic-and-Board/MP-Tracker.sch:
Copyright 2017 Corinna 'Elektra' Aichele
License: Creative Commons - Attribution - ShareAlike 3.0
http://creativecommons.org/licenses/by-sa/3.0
